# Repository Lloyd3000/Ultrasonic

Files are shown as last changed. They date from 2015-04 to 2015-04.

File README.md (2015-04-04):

# Ultrasonic Music Control

A small, driverless device that allows you to control your music with the wave of a hand.

This is a small device that youses the off the shelf Ultra sonic module "HC-SR04" and an Attiny 2313 to create, with the help of the VUSB library a Gesture Control interface for the Music control functions on your PC
!

Full text on "https://hackaday.io/project/2632-ultrasonic-music-control"

My Website "http://www.lloyd3000.com"

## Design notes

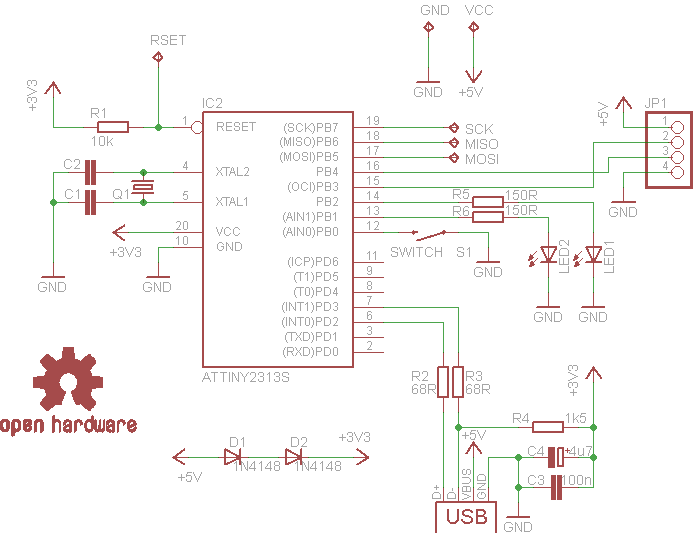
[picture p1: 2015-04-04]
Hardware/cuirit diagramm.png

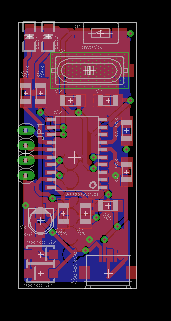
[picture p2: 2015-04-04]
Hardware/pcb.png

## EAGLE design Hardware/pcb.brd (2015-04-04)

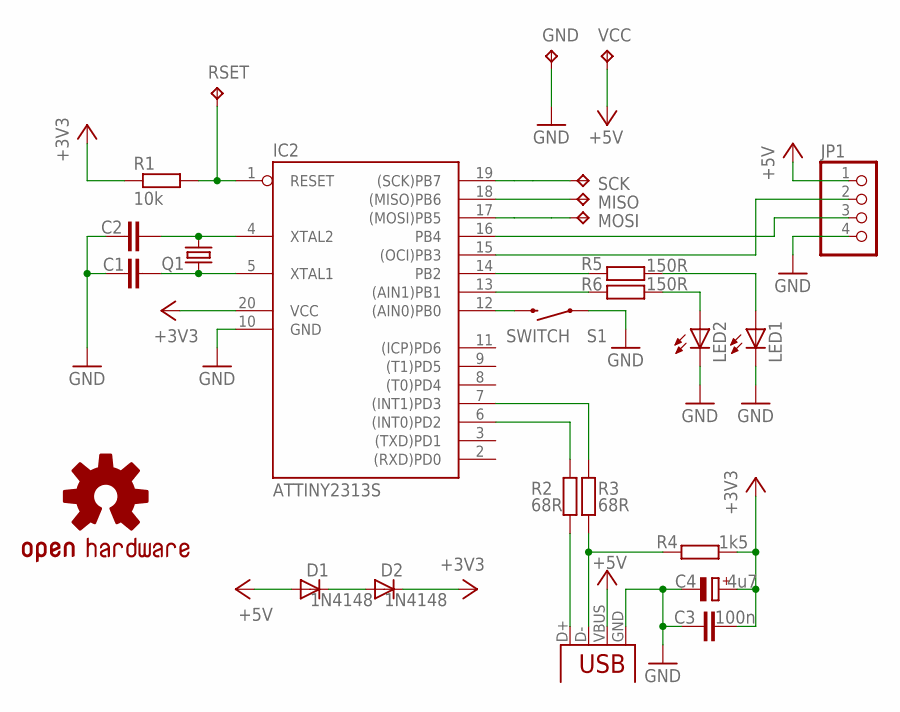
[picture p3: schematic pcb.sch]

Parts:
C1, C2: C-EUC1206; C1206
C3: 100n; C1206
C4: 4u7; PANASONIC_B
D1, D2: 1N4148; SMA-DIODE
GND: TPB2,54; B2,54
IC2: ATTINY2313S; SO20L
JP1: PINHD-1X4_2.54; 1X04
LED1, LED2: LED1206; LED-1206
LOGO1: OSHW-LOGOM; OSHW-LOGO-M
MISO: TPB2,54; B2,54
MOSI: TPB2,54; B2,54
Q1: CRYSTALSMD; HC49UP
R1: 10k; R1206
R2, R3: 68R; R1206
R4: 1k5; R1206
R5, R6: 150R; R1206
RSET: TPB2,54; B2,54
S1: SWITCH; TACTILE-SWITCH-1101NE
SCK: TPB2,54; B2,54
VCC: TPB2,54; B2,54
X1: USB-MICROB

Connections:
+3V3: C3.2, C4.+, D2.C, IC2.20 (VCC), R1.1, R4.1
+5V: D1.A, JP1.1, VCC.TP, X1.VBUS
GND: C1.1, C2.1, C3.1, C4.-, GND.TP, IC2.10 (GND), JP1.4, LED1.C, LED2.C, S1.P$1 (1), X1.GND
unnamed: C1.2, IC2.5 (XTAL1), Q1.1
unnamed: C2.2, IC2.4 (XTAL2), Q1.2
unnamed: IC2.1 (RESET), R1.2, RSET.TP
unnamed: LED2.A, R6.2
unnamed: IC2.14 (PB2), R5.1
unnamed: IC2.13 ((AIN1)PB1), R6.1
unnamed: LED1.A, R5.2
unnamed: R2.1, X1.D+
unnamed: R3.1, R4.2, X1.D-
unnamed: IC2.12 ((AIN0)PB0), S1.P$2 (2)
unnamed: IC2.15 ((OCI)PB3), JP1.2
unnamed: IC2.16 (PB4), JP1.3
unnamed: IC2.6 ((INT0)PD2), R2.2
unnamed: IC2.7 ((INT1)PD3), R3.2
unnamed: D1.C, D2.A
unnamed: IC2.19 ((SCK)PB7), SCK.TP
unnamed: IC2.18 ((MISO)PB6), MISO.TP
unnamed: IC2.17 ((MOSI)PB5), MOSI.TP

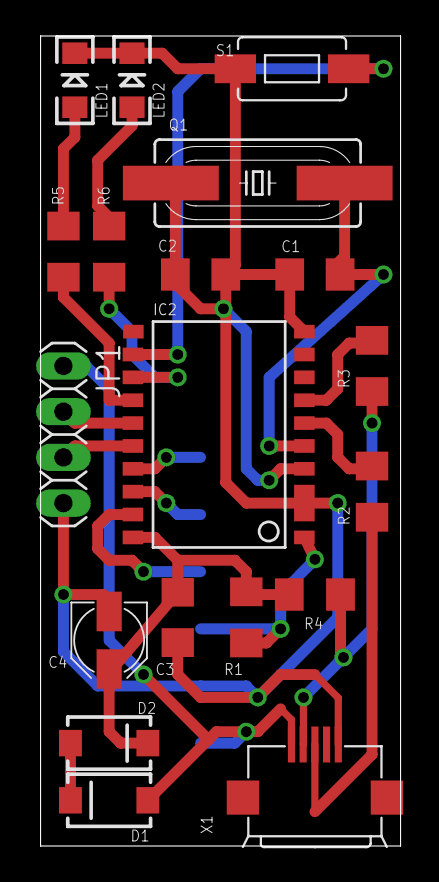
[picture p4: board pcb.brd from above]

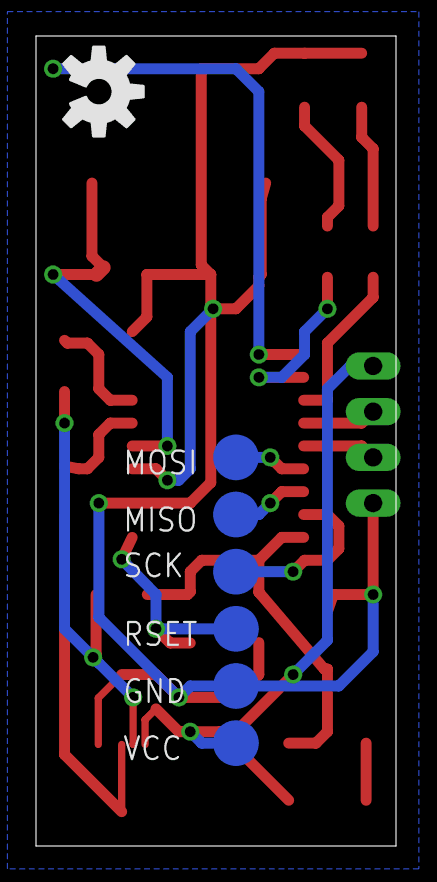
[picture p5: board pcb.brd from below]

Board: 2 copper layers, 20.0 x 45.0 mm, 26 parts (7 on the bottom side), 21 nets.

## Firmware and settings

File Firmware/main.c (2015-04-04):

/*************************************************************************
Title:    Ultrasonic Volume Control
Author:   Elias Fröhlich 
Web: http://hackaday.io/project/2632-Ultrasonic-Volume-Control
**************************************************************************/

#define f_cpu 16000000
#include <avr/io.h>
#include <avr/interrupt.h>
#include <avr/wdt.h>
#include <util/delay.h>

#include "usbdrv.h"

//The USB Hid Report Handler that tells the PC what data to expect
PROGMEM char usbHidReportDescriptor[USB_CFG_HID_REPORT_DESCRIPTOR_LENGTH] = {
    0x05, 0x0c,                    // USAGE_PAGE (Consumer Devices)
    0x09, 0x01,                    // USAGE (Consumer Control)
    0xa1, 0x01,                    // COLLECTION (Application)
    0x85, 0x01,                    //   REPORT_ID (1)
    0x19, 0x00,                    //   USAGE_MINIMUM (Unassigned)
    0x2a, 0x3c, 0x02,              //   USAGE_MAXIMUM (AC Format)
    0x15, 0x00,                    //   LOGICAL_MINIMUM (0)
    0x26, 0x3c, 0x02,              //   LOGICAL_MAXIMUM (572)
    0x95, 0x01,                    //   REPORT_COUNT (1)
    0x75, 0x10,                    //   REPORT_SIZE (16)
    0x81, 0x00,                    //   INPUT (Data,Var,Abs)
    0xc0                           // END_COLLECTION  
};

//Declare some variables
typedef struct {
	uint8_t modifier;
	uint8_t reserved;
	uint8_t keycode[2];
} keyboard_report_t;

static uchar reportBuffer[3] = {0,0,0} ;
volatile int test;
volatile uchar KeyPressed = 0;
static keyboard_report_t keyboard_report; 

static uchar idleRate; 


//set up the USB connection
usbMsgLen_t usbFunctionSetup(uchar data[8]) {
    usbRequest_t *rq = (void *)data;

    if((rq->bmRequestType & USBRQ_TYPE_MASK) == USBRQ_TYPE_CLASS) {
        switch(rq->bRequest) {
        case USBRQ_HID_GET_REPORT: // send "no keys pressed" if asked here
            // wValue: ReportType (highbyte), ReportID (lowbyte)
            usbMsgPtr = (void *)&keyboard_report; // we only have this one
            keyboard_report.modifier = 0;
            keyboard_report.keycode[0] = 0;
            return sizeof(keyboard_report);
		case USBRQ_HID_SET_REPORT: // if wLength == 1, should be LED state
            return (rq->wLength.word == 1) ? USB_NO_MSG : 0;
        case USBRQ_HID_GET_IDLE: // send idle rate to PC as required by spec
            usbMsgPtr = &idleRate;
            return 1;
        case USBRQ_HID_SET_IDLE: // save idle rate as required by spec
            idleRate = rq->wValue.bytes[1];
            return 0;
        }
    }
    
    return 0; // by default don't return any data
}


int main() {

	unsigned int count;
	
	int i;
	
	unsigned char  set = 0, send = 0, on = 1, times = 1;
	
	DDRB = 0b00001110; // PB1,2,3 as output rest is input
	PORTB |= 1 << PB0; // PB0 is input with internal pullup resistor activated
	PORTB |= 1 << PB4; // PB4 is input with internal pullup resistor activated    
    wdt_enable(WDTO_1S); // enable 1s watchdog timer

	PORTB |= (1 << PB2); //LED1 on
	PORTB &= ~(1 << PB1);  //LED2 off
			
    usbInit();
	
    usbDeviceDisconnect(); // enforce re-enumeration
    for(i = 0; i<250; i++) { // wait 500 ms
        wdt_reset(); // keep the watchdog happy
        _delay_ms(2);
    }
	
    usbDeviceConnect();
	
	reportBuffer[0] = 1;  // ReportID = 1
	reportBuffer[2] = 0;  
	
  
    sei(); // Enable interrupts after re-enumeration
	
    while(1) {
        wdt_reset(); // keep the watchdog happy
        usbPoll();

			
		if(!(PINB & (1<<PB0))) { // button pressed (PB1 at ground voltage)
			
			 if(on == 1){
			on = 0;
			PORTB &= ~(1 << PB2); // Triggerline turn on	
			PORTB |= (1 << PB1); 
			}
			else{
			PORTB |= (1 << PB2); 
			PORTB &= ~(1 << PB1); // Triggerline turn on	
			on = 1;
			}
		
			for(i = 0; i<250; i++) { // wait 500 ms
			usbPoll();
			wdt_reset(); // keep the watchdog happy
			_delay_ms(2);
			} 
			
		}


		if(on == 1){
		
		
		//Sending th trig signal
		PORTB |= (1 << PB3); 
		_delay_us(10);
		PORTB &= ~(1 << PB3);


		//Polling the Input pin
		for(i = 0; i<1250; i++) { 
		
			wdt_reset(); // keep the watchdog happy
			usbPoll();
	
			if((PINB & (1<<PB4))){
			count ++;

			}else{

			}
			_delay_us(5);
		}	



		//what key is pressed?
		
		if((count <= 80)&(set == 0)){
		
			KeyPressed = 0xCD;
			send = 1;
			times = 1;
			set = 1;
			
		}else if((count >= 81) & (count <= 140)){

			KeyPressed = 0xEA;
			send = 1;
			times = 10;
			
		}else if((count >= 140) & (count <= 258)){

			KeyPressed = 0xE9;
			send = 1;
			times = 10;
			
		}else{

			set = 0;
		
		} 
		
		
	//Send the KEy
		if((send == 1)){
		

			
		while(times>=1){
				usbPoll();
				wdt_reset(); // keep the watchdog happy		
			times --;
			
			reportBuffer[1] = KeyPressed;
			usbSetInterrupt(reportBuffer, sizeof(reportBuffer));
			
			_delay_ms(10); //	
							 			
			reportBuffer[1] = 0x00;
			usbSetInterrupt(reportBuffer, sizeof(reportBuffer));
			
			_delay_ms(10); //		 
		}

		PORTB |= (1 << PB1); //LED on
		PORTB |= (1 << PB2); //LED on

			for(i = 0; i<150; i++) { // wait 300 ms
				usbPoll();
				wdt_reset(); // keep the watchdog happy
				_delay_ms(2);
			}
			
			PORTB &= ~(1 << PB1); // Triggerline turn on	
			PORTB |= (1 << PB2); 		
			
		send = 0;
		
		}
		
		}
		
		
		count = 0;
		

		
		
    }
	
    return 0;
}

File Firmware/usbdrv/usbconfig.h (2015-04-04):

/* Name: usbconfig.h
 * Project: V-USB, virtual USB port for Atmel's(r) AVR(r) microcontrollers
 * Author: Christian Starkjohann
 * Creation Date: 2005-04-01
 * Tabsize: 4
 * Copyright: (c) 2005 by OBJECTIVE DEVELOPMENT Software GmbH
 * License: GNU GPL v2 (see License.txt), GNU GPL v3 or proprietary (CommercialLicense.txt)
 * This Revision: $Id$
 */

#ifndef __usbconfig_h_included__
#define __usbconfig_h_included__

/*
General Description:
This file is an example configuration (with inline documentation) for the USB
driver. It configures V-USB for USB D+ connected to Port D bit 2 (which is
also hardware interrupt 0 on many devices) and USB D- to Port D bit 4. You may
wire the lines to any other port, as long as D+ is also wired to INT0 (or any
other hardware interrupt, as long as it is the highest level interrupt, see
section at the end of this file).
*/

/* ---------------------------- Hardware Config ---------------------------- */

#define USB_CFG_IOPORTNAME      D
/* This is the port where the USB bus is connected. When you configure it to
 * "B", the registers PORTB, PINB and DDRB will be used.
 */
#define USB_CFG_DMINUS_BIT      3
/* This is the bit number in USB_CFG_IOPORT where the USB D- line is connected.
 * This may be any bit in the port.
 */
#define USB_CFG_DPLUS_BIT       2
/* This is the bit number in USB_CFG_IOPORT where the USB D+ line is connected.
 * This may be any bit in the port. Please note that D+ must also be connected
 * to interrupt pin INT0! [You can also use other interrupts, see section
 * "Optional MCU Description" below, or you can connect D- to the interrupt, as
 * it is required if you use the USB_COUNT_SOF feature. If you use D- for the
 * interrupt, the USB interrupt will also be triggered at Start-Of-Frame
 * markers every millisecond.]
 */
#define USB_CFG_CLOCK_KHZ       16000
/* Clock rate of the AVR in kHz. Legal values are 12000, 12800, 15000, 16000,
 * 16500, 18000 and 20000. The 12.8 MHz and 16.5 MHz versions of the code
 * require no crystal, they tolerate +/- 1% deviation from the nominal
 * frequency. All other rates require a precision of 2000 ppm and thus a
 * crystal!
 * Since F_CPU should be defined to your actual clock rate anyway, you should
 * not need to modify this setting.
 */
#define USB_CFG_CHECK_CRC       0
/* Define this to 1 if you want that the driver checks integrity of incoming
 * data packets (CRC checks). CRC checks cost quite a bit of code size and are
 * currently only available for 18 MHz crystal clock. You must choose
 * USB_CFG_CLOCK_KHZ = 18000 if you enable this option.
 */

/* ----------------------- Optional Hardware Config ------------------------ */

/* #define USB_CFG_PULLUP_IOPORTNAME   D */
/* If you connect the 1.5k pullup resistor from D- to a port pin instead of
 * V+, you can connect and disconnect the device from firmware by calling
 * the macros usbDeviceConnect() and usbDeviceDisconnect() (see usbdrv.h).
 * This constant defines the port on which the pullup resistor is connected.
 */
/* #define USB_CFG_PULLUP_BIT          4 */
/* This constant defines the bit number in USB_CFG_PULLUP_IOPORT (defined
 * above) where the 1.5k pullup resistor is connected. See description
 * above for details.
 */

/* --------------------------- Functional Range ---------------------------- */
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

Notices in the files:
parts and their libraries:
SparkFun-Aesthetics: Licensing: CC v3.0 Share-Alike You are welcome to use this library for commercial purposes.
